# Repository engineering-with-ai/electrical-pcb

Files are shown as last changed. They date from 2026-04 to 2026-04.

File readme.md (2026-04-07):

# [electrical-pcb] ⚡




CM4 carrier board — Raspberry Pi Compute Module 4 carrier for an outdoor self-contained sensor system with computer vision, thermal imaging, cellular uplink, and solar + battery power. 5V screw terminal input, polyfuse + reverse polarity protection, CP2102N USB-UART debug, MAX3485 RS-485, I2C/SPI/GPIO headers on 2.54mm pitch, 100x80mm 2-layer board.

Foundation board that exposes raw CM4 interfaces via headers. Downstream boards connect RGB camera (CSI), FLIR Lepton thermal sensor (SPI), cellular modem (RS-485 Modbus), and solar charge controller (I2C BMS telemetry).

**[View generated deliverables](output/)**

## 📋 Board Spec

```mermaid
graph LR
    PWR["5V Screw Terminal"] --> FUSE["Polyfuse<br/>1812L200 2A"]
    FUSE --> FET["SI2301 P-FET<br/>Reverse Polarity"]
    FET --> RAIL["5V_RAIL"]
    RAIL --> CM4["CM4 Module<br/>Hirose DF40"]
    CM4 --> UART["CP2102N<br/>USB-UART Debug"]
    CM4 --> RS485["MAX3485<br/>RS-485"]
    CM4 --> I2C["I2C Header<br/>2.2k Pull-ups"]
    CM4 --> SPI["SPI Header"]
    CM4 --> GPIO["GPIO Header"]

    style PWR fill:#4a9,stroke:#333
    style FUSE fill:#a94,stroke:#333
    style FET fill:#a94,stroke:#333
    style RAIL fill:#4a9,stroke:#333
    style CM4 fill:#49a,stroke:#333
    style UART fill:#94a,stroke:#333
    style RS485 fill:#94a,stroke:#333
    style I2C fill:#94a,stroke:#333
    style SPI fill:#94a,stroke:#333
    style GPIO fill:#94a,stroke:#333
```

## 🔄 Workflow

```
theory.ipynb (sympy + pint) -> cad/model.py (SKiDL -> netlist) -> sim/ (power + signal integrity) -> pytest (assert vs theory)
```

1. `theory.ipynb` derives power rail budget, polyfuse margin, I2C pull-up selection, RS-485 bias
2. `cad/model.py` defines circuit in SKiDL, generates KiCad netlist
3. `sim/model.py` validates power rail voltage, I2C rise time, RS-485 bias
4. `sim/test_run.py` asserts simulation matches theory within tolerance
5. `/generate-schematic` generates professional `.kicad_sch` from netlist + `layout_spec.yaml`

## 🚀 Quick Start

```bash
uv sync
uv run poe checks          # black + ruff lint
uv run poe notebook         # execute theory.ipynb
uv run poe build            # SKiDL -> KiCad netlist + schematic
uv run poe sim              # 4/4 tests pass
```

## 🏭 Code to Fabrication

Everything is CLI or Claude skill except 3 manual steps marked with a wrench.

```
 1. uv run poe build                 → SKiDL netlist + schematic
 2. uv run poe sim                   → 4/4 tests pass
 3. /generate-schematic              → professional .kicad_sch
 4. uv run poe validate-model        → ERC 0 errors
 5. uv run poe generate-model        → schematic SVG + dark SVG + drawing PDF

    ┌──────────────────────────────────────────────────────┐
    │  HUMAN : open pcbnew, press F8, save, close          │
    └──────────────────────────────────────────────────────┘

 6. /layout-pcb                      → place + autoroute + ground pour + DRC + review SVG

    ┌──────────────────────────────────────────────────────┐
    │  HUMAN: review SVG, tweak pcb_placement.yaml, re-run │
    └──────────────────────────────────────────────────────┘

 7. uv run poe validate-asm          → DRC 0 errors
 8. uv run poe generate-asm          → gerbers + BOM + CPL + STEP
```

## 📁 Structure

- `theory.ipynb` — power budget + signal integrity derivation
- `sim/` — simulation + pytest assertions against theory
- `cad/netlist/` — SKiDL circuit definition (model.py, power.py, comms.py, io_headers.py)
- `cad/layout_spec.yaml` — schematic layout + block definitions
- `cad/pcb_placement.yaml` — AI-generated PCB component positions
- `cad/drawing-sheet.kicad_wks` — custom EWAI title block
- `cad/drawing/` — SVG dark mode conversion, PCB placement script
- `output/drawings/` — schematic SVGs (light + dark), drawing PDF
- `output/gerbers/` — fabrication gerbers + drill files
- `output/fab/` — BOM, CPL for assembly

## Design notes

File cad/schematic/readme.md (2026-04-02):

# cad/schematic/

Auto-generated by `/generate-schematic` — do not edit manually.
All `.py` files in this directory are replaced entirely each time the skill runs.

Run `/generate-schematic` to populate.

## Generated Files

| File | Purpose |
|---|---|
| `schematic.py` | Orchestrator — reads layout_spec.yaml, calls block placers, saves .kicad_sch |
| `sch_helpers.py` | Pin offsets, wiring utilities, power/label stub helpers |
| `sch_power.py` | Power input block (screw terminal, polyfuse, reverse polarity, bulk caps) |
| `sch_mcu.py` | MCU/processor connector block |
| `sch_comms.py` | Communication blocks (UART, RS-485, USB, CAN, etc.) |
| `sch_io.py` | I/O header blocks (I2C, SPI, GPIO, decoupling) |

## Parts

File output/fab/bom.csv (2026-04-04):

Designator | Comment | Footprint | Quantity
C1 | 100uF | Capacitor_SMD:C_1210_3225Metric | 1
C2 | 10uF | Capacitor_SMD:C_0805_2012Metric | 1
C3-C8 | 100nF | Capacitor_SMD:C_0402_1005Metric | 6
F1 | 2A | Fuse:Fuse_1812_4532Metric | 1
J1 | 5V_IN | Connector_PinHeader_2.54mm:PinHeader_1x02_P2.54mm_Vertical | 1
J2 | CM4 | Connector_PinHeader_2.54mm:PinHeader_2x20_P2.54mm_Vertical | 1
J3 | RS485 | Connector_PinHeader_2.54mm:PinHeader_1x04_P2.54mm_Vertical | 1
J4 | USB_DEBUG | Connector_USB:USB_Micro-B_Molex_47346-0001 | 1
J5 | I2C | Connector_PinHeader_2.54mm:PinHeader_1x04_P2.54mm_Vertical | 1
J6 | SPI | Connector_PinHeader_2.54mm:PinHeader_1x06_P2.54mm_Vertical | 1
J7 | GPIO | Connector_PinHeader_2.54mm:PinHeader_1x08_P2.54mm_Vertical | 1
Q1 | SI2301 | Package_TO_SOT_SMD:SOT-23 | 1
R1 | 120 | Resistor_SMD:R_0805_2012Metric | 1
R2,R3 | 560 | Resistor_SMD:R_0603_1608Metric | 2
R4,R5 | 2.2k | Resistor_SMD:R_0603_1608Metric | 2
U1 | MAX3485 | Package_SO:SOIC-8_3.9x4.9mm_P1.27mm | 1
U2 | CP2102N | Package_DFN_QFN:QFN-20-1EP_4x4mm_P0.5mm_EP2.5x2.5mm | 1

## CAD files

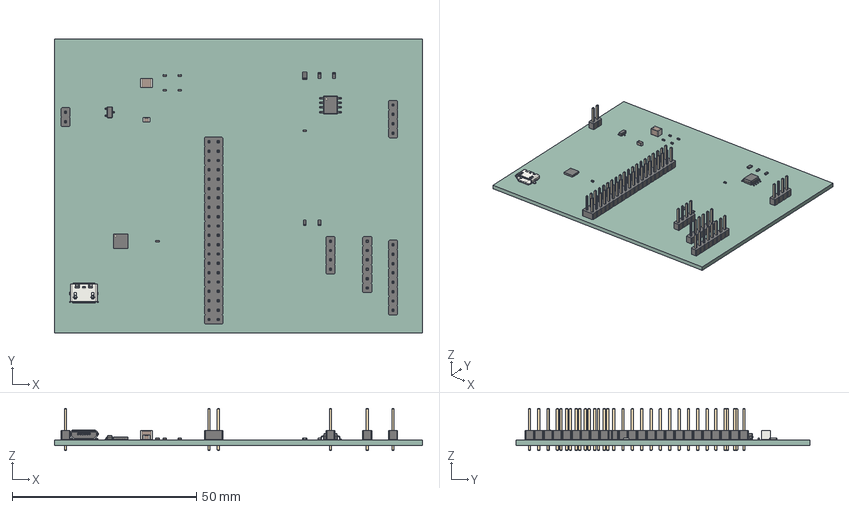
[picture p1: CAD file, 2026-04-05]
output/cm4_carrier_pcb.step
100.0 x 80.0 x 11.5 mm
C_0402_1005Metric x 6
USB_Micro-B_Molex_47346-0001
R_0603_1608Metric x 4
PinHeader_2x20_P2.54mm_Vertical
PinHeader_1x02_P2.54mm_Vertical
PinHeader_1x04_P2.54mm_Vertical x 2
C_0805_2012Metric
PinHeader_1x08_P2.54mm_Vertical
SOIC-8_3.9x4.9mm_P1.27mm
QFN-20-1EP_4x4mm_P0.5mm_EP2.5x2.5mm
PinHeader_1x06_P2.54mm_Vertical
SOT-23
R_0805_2012Metric
C_1210_3225Metric
cm4_carrier_PCB

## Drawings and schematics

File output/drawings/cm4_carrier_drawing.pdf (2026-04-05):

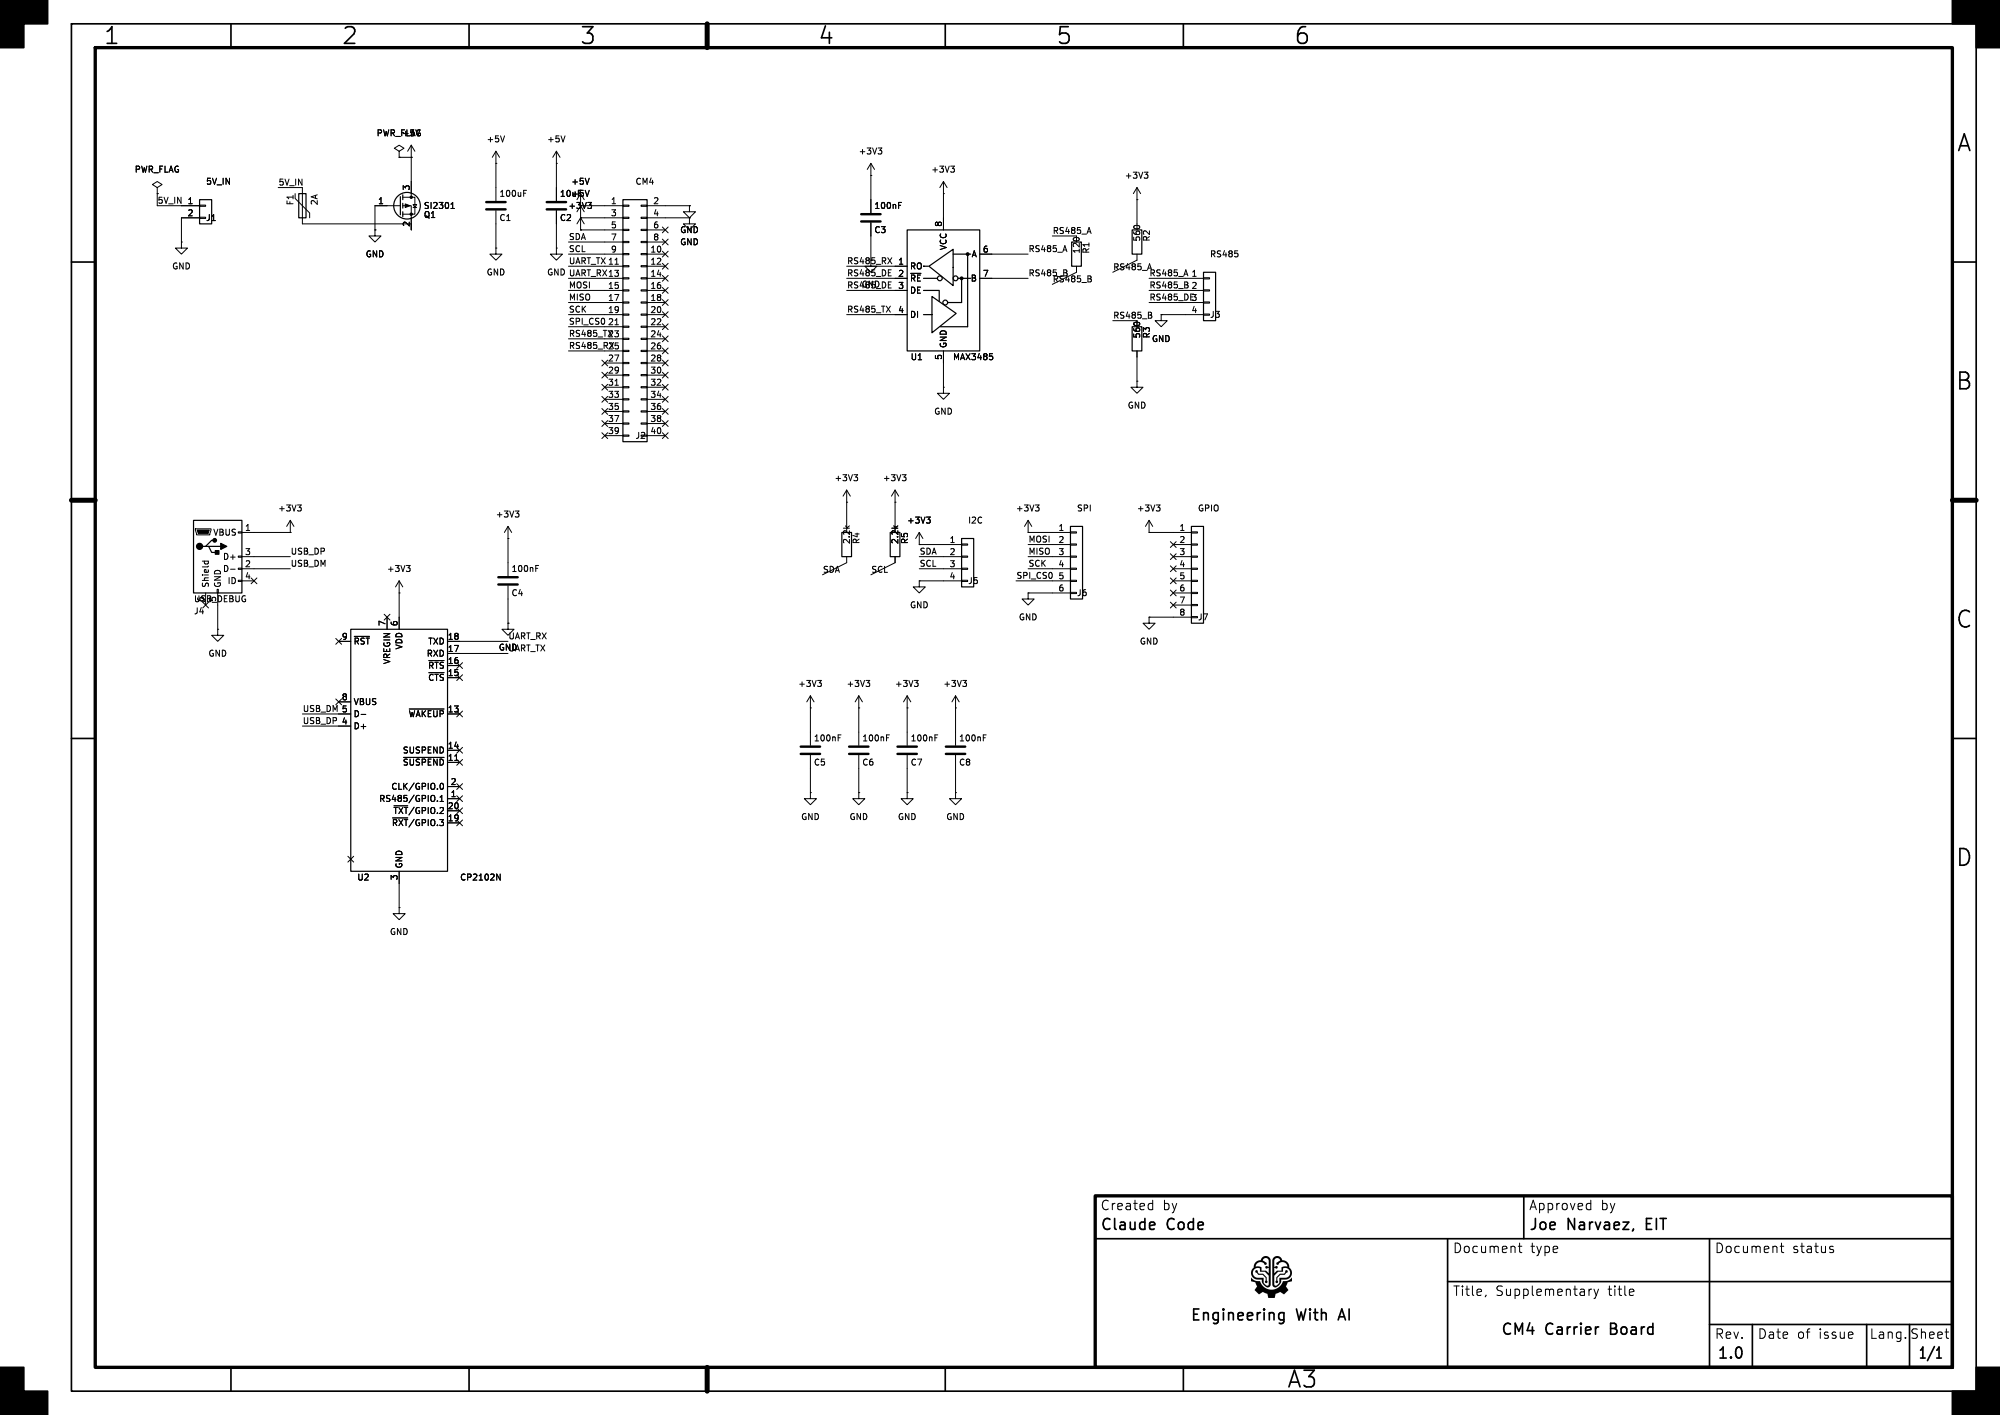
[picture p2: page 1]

3 TXD 18 RXD 17 ~{RTS} 16 ~{CTS} 15 ~{WAKEUP} 13 SUSPEND 14 ~{SUSPEND}11 CLK/GPIO.0 2 RS485/GPIO.1 1 ~{TXT}/GPIO.220 ~{RXT}/GPIO.319 U2 CP2102N GND

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

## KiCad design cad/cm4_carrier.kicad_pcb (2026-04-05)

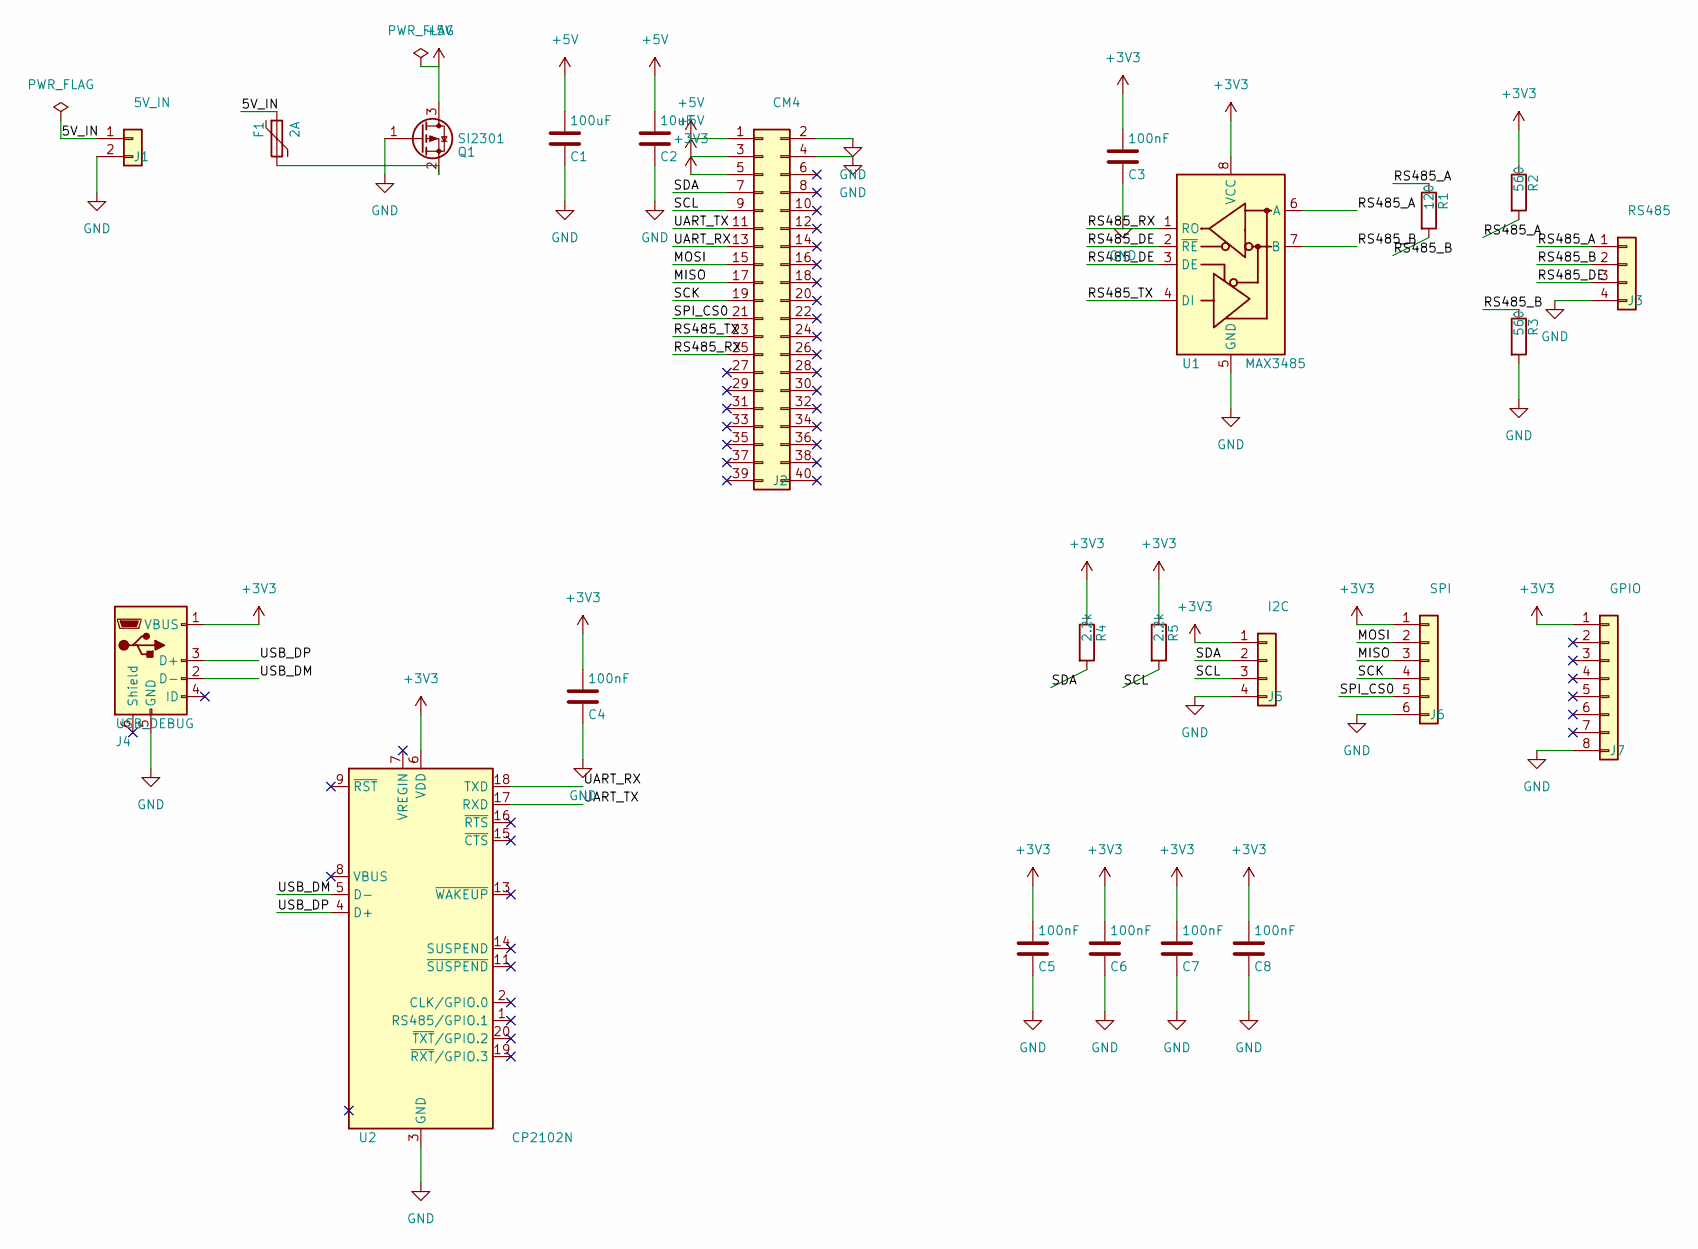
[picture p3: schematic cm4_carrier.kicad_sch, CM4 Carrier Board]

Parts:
C1: 100uF; C_1210_3225Metric
C2: 10uF; C_0805_2012Metric
C3, C4, C5, C6, C7, C8: 100nF; C_0402_1005Metric
F1: 2A; Fuse_1812_4532Metric
J1: 5V_IN; PinHeader_1x02_P2.54mm_Vertical
J2: CM4; PinHeader_2x20_P2.54mm_Vertical
J3: RS485; PinHeader_1x04_P2.54mm_Vertical
J4: USB_DEBUG; USB_Micro-B_Molex_47346-0001
J5: I2C; PinHeader_1x04_P2.54mm_Vertical
J6: SPI; PinHeader_1x06_P2.54mm_Vertical
J7: GPIO; PinHeader_1x08_P2.54mm_Vertical
Q1: SI2301; SOT-23
R1: 120; R_0805_2012Metric
R2, R3: 560; R_0603_1608Metric
R4, R5: 2.2k; R_0603_1608Metric
U1: MAX3485; SOIC-8_3.9x4.9mm_P1.27mm
U2: CP2102N; QFN-20-1EP_4x4mm_P0.5mm_EP2.5x2.5mm

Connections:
+3V3: C3.1, C4.1, C5.1, C6.1, C7.1, C8.1, J2.5, J4.1 (VBUS), J5.1, J6.1, J7.1, R2.1, R4.1, R5.1, U1.8 (VCC), U2.6 (VDD)
+5V: C1.1, C2.1, J2.1, J2.3, Q1.3 (D)
/5V_IN: F1.1, J1.1
/MISO: J2.17, J6.3
/MOSI: J2.15, J6.2
/RS485_A: J3.1, R1.1, R2.2, U1.6 (A)
/RS485_B: J3.2, R1.2, R3.1, U1.7 (B)
/RS485_DE: J3.3, U1.2 (~RE), U1.3 (DE)
/RS485_RX: J2.25, U1.1 (RO)
/RS485_TX: J2.23, U1.4 (DI)
/SCK: J2.19, J6.4
/SCL: J2.9, J5.3, R5.2
/SDA: J2.7, J5.2, R4.2
/SPI_CS0: J2.21, J6.5
/UART_RX: J2.13, U2.18 (TXD)
/UART_TX: J2.11, U2.17 (RXD)
/USB_DM: J4.2 (D-), U2.5 (D-)
/USB_DP: J4.3 (D+), U2.4 (D+)
GND: C1.2, C2.2, C3.2, C4.2, C5.2, C6.2, C7.2, C8.2, J1.2, J2.2, J2.4, J3.4, J4.5 (GND), J5.4, J6.6, J7.8, Q1.1 (G), R3.2, U1.5 (GND), U2.3 (GND), U2.12 (GND), U2.21 (GND)
unnamed: F1.2, Q1.2 (S)

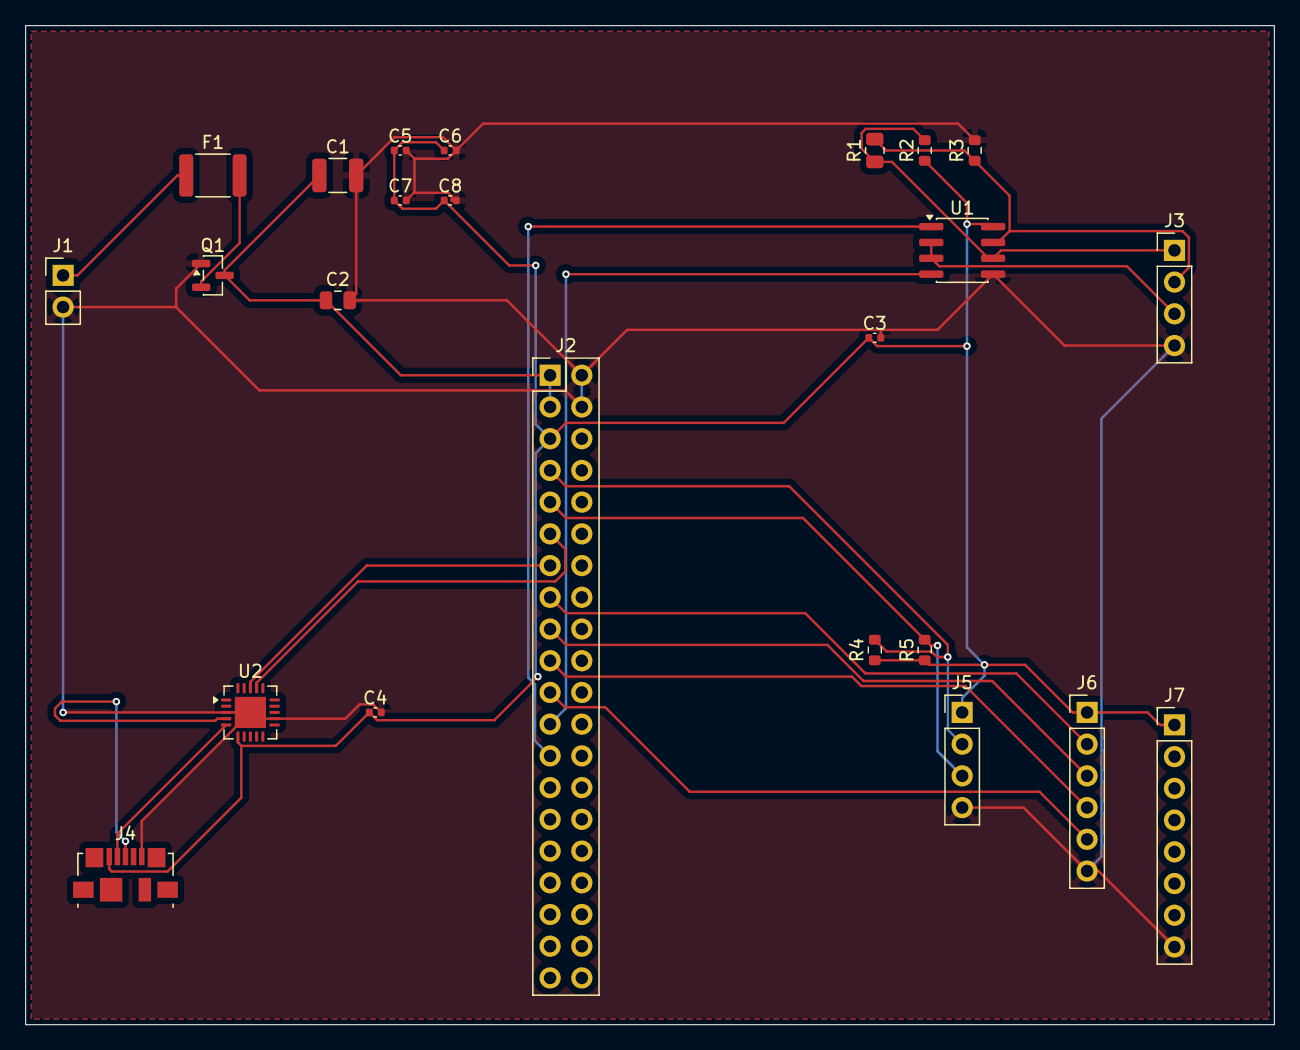
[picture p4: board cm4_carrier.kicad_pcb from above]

Board: 2 copper layers, 100.0 x 80.0 mm, 24 parts (0 on the bottom side), 20 nets.

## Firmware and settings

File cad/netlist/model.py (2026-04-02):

"""CM4 carrier board netlist generation.

SKiDL defines the circuit topology -> KiCad netlist.
Modular: power, comms, and I/O sections in separate files.
"""

import os

_SYM_DIR = "/usr/share/kicad/symbols"
for v in (
    "KICAD_SYMBOL_DIR",
    "KICAD6_SYMBOL_DIR",
    "KICAD7_SYMBOL_DIR",
    "KICAD8_SYMBOL_DIR",
    "KICAD9_SYMBOL_DIR",
):
    os.environ[v] = _SYM_DIR

import skidl  # noqa: E402

from cad.netlist.comms import build_rs485, build_usb_uart  # noqa: E402
from cad.netlist.io_headers import (  # noqa: E402
    build_gpio_header,
    build_i2c_header,
    build_spi_header,
)
from cad.netlist.power import build_power  # noqa: E402

NETLIST_PATH = "cad/cm4_carrier.net"


def build_netlist() -> None:
    """Define CM4 carrier board in SKiDL and generate KiCad netlist."""
    v5_in = skidl.Net("5V_IN")
    v5_rail = skidl.Net("5V_RAIL")
    v3v3 = skidl.Net("3V3")
    gnd = skidl.Net("GND")

    uart_tx = skidl.Net("UART_TX")
    uart_rx = skidl.Net("UART_RX")
    sda = skidl.Net("SDA")
    scl = skidl.Net("SCL")
    mosi = skidl.Net("MOSI")
    miso = skidl.Net("MISO")
    sck = skidl.Net("SCK")
    cs = skidl.Net("SPI_CS0")
    rs485_tx = skidl.Net("RS485_TX")
    rs485_rx = skidl.Net("RS485_RX")

    build_power(v5_in, v5_rail, gnd)
    _build_cm4_connector(
        v5_rail,
        v3v3,
        gnd,
        uart_tx,
        uart_rx,
        sda,
        scl,
        mosi,
        miso,
        sck,
        cs,
        rs485_tx,
        rs485_rx,
    )
    build_rs485(rs485_tx, rs485_rx, v3v3, gnd)
    build_usb_uart(uart_tx, uart_rx, v3v3, gnd)
    build_i2c_header(sda, scl, v3v3, gnd)
    build_spi_header(mosi, miso, sck, cs, v3v3, gnd)
    build_gpio_header(v3v3, gnd)
    _build_decoupling(v3v3, gnd, count=4)

    skidl.generate_netlist(file_=NETLIST_PATH, tool=skidl.KICAD8)


def _build_cm4_connector(
    v5_rail: skidl.Net,
    v3v3: skidl.Net,
    gnd: skidl.Net,
    uart_tx: skidl.Net,
    uart_rx: skidl.Net,
    sda: skidl.Net,
    scl: skidl.Net,
    mosi: skidl.Net,
    miso: skidl.Net,
    sck: skidl.Net,
    cs: skidl.Net,
    rs485_tx: skidl.Net,
    rs485_rx: skidl.Net,
) -> None:
    """CM4 module connector — 2x20 header as DF40 placeholder."""
    # Reason: Hirose DF40 100-pin not in standard KiCad libs
    j = skidl.Part(
        "Connector_Generic",
        "Conn_02x20_Odd_Even",
        footprint="Connector_PinHeader_2.54mm:PinHeader_2x20_P2.54mm_Vertical",
    )
    j.value = "CM4"
    # Reason: pin assignments per RPi CM4 datasheet GPIO header
    v5_rail += j[1]
    gnd += j[2]
    v5_rail += j[3]
    gnd += j[4]
    v3v3 += j[5]
    sda += j[7]
    scl += j[9]
    uart_tx += j[11]
    uart_rx += j[13]
    mosi += j[15]
    miso += j[17]
    sck += j[19]
    cs += j[21]
    rs485_tx += j[23]
    rs485_rx += j[25]


def _build_decoupling(v3v3: skidl.Net, gnd: skidl.Net, count: int) -> None:
    """Add 100nF decoupling caps for CM4."""
    for _ in range(count):
        c = skidl.Part(
            "Device",
            "C",
            value="100nF",
            footprint="Capacitor_SMD:C_0402_1005Metric",
        )
        v3v3 += c[1]
        gnd += c[2]


if __name__ == "__main__":
    build_netlist()
    print(f"Netlist: {NETLIST_PATH}")

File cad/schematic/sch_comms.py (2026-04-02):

# AUTO-GENERATED by /generate-schematic — do not edit manually.
# This file is replaced entirely each time the skill runs for a new circuit.
"""Communication blocks: RS-485 (MAX3485) and USB-UART (CP2102N)."""

from cad.schematic.sch_helpers import (
    CP2102N_PINS,
    MAX3485_PINS,
    USB_MICRO_PINS,
    c_pin,
    conn_1xn_pin,
    ic_pin,
    nc,
    r_pin,
    stub_label,
    stub_pwr,
)

FP_SOIC8 = "Package_SO:SOIC-8_3.9x4.9mm_P1.27mm"
FP_R_0805 = "Resistor_SMD:R_0805_2012Metric"
FP_R_0603 = "Resistor_SMD:R_0603_1608Metric"
FP_CONN_1X04 = "Connector_PinHeader_2.54mm:PinHeader_1x04_P2.54mm_Vertical"
FP_C_0402 = "Capacitor_SMD:C_0402_1005Metric"
FP_QFN20 = "Package_DFN_QFN:QFN-20-1EP_4x4mm_P0.5mm_EP2.5x2.5mm"
FP_USB_MICRO = "Connector_USB:USB_Micro-B_Molex_47346-0001"


def place_rs485_block(sch, bx: int, by: int, pwr: dict) -> None:
    """Place RS-485 transceiver block."""
    u1_pos = (bx + 22, by + 20)
    u1 = sch.components.add("Interface_UART:MAX3485", "U1", "MAX3485", position=u1_pos)
    u1.footprint = FP_SOIC8

    stub_label(sch, ic_pin(u1_pos, MAX3485_PINS, 1), "RS485_RX", dx=-8)
    stub_label(sch, ic_pin(u1_pos, MAX3485_PINS, 2), "RS485_DE", dx=-8)
    stub_label(sch, ic_pin(u1_pos, MAX3485_PINS, 3), "RS485_DE", dx=-8)
    stub_label(sch, ic_pin(u1_pos, MAX3485_PINS, 4), "RS485_TX", dx=-8)
    stub_pwr(sch, ic_pin(u1_pos, MAX3485_PINS, 8), "power:+3V3", pwr, dy=-4)
    stub_pwr(sch, ic_pin(u1_pos, MAX3485_PINS, 5), "power:GND", pwr, dy=4)
    stub_label(sch, ic_pin(u1_pos, MAX3485_PINS, 6), "RS485_A", dx=6, rotation=180)
    stub_label(sch, ic_pin(u1_pos, MAX3485_PINS, 7), "RS485_B", dx=6, rotation=180)

    r1_pos = (bx + 44, by + 14)
    r1 = sch.components.add("Device:R", "R1", "120", position=r1_pos)
    r1.footprint = FP_R_0805
    stub_label(sch, r_pin(r1_pos, 2), "RS485_A", dx=-4)
    stub_label(sch, r_pin(r1_pos, 1), "RS485_B", dx=-4, dy=2)

    r2_pos = (bx + 54, by + 12)
    r2 = sch.components.add("Device:R", "R2", "560", position=r2_pos)
    r2.footprint = FP_R_0603
    stub_pwr(sch, r_pin(r2_pos, 2), "power:+3V3", pwr, dy=-4)
    stub_label(sch, r_pin(r2_pos, 1), "RS485_A", dx=-4, dy=2)

    r3_pos = (bx + 54, by + 28)
    r3 = sch.components.add("Device:R", "R3", "560", position=r3_pos)
    r3.footprint = FP_R_0603
    stub_label(sch, r_pin(r3_pos, 2), "RS485_B", dx=-4)
    stub_pwr(sch, r_pin(r3_pos, 1), "power:GND", pwr, dy=4)

    j3_pos = (bx + 66, by + 20)
    j3 = sch.components.add(
        "Connector_Generic:Conn_01x04", "J3", "RS485", position=j3_pos
    )
    j3.footprint = FP_CONN_1X04
    stub_label(sch, conn_1xn_pin(j3_pos, 4, 1), "RS485_A", dx=-6)
    stub_label(sch, conn_1xn_pin(j3_pos, 4, 2), "RS485_B", dx=-6)
    stub_label(sch, conn_1xn_pin(j3_pos, 4, 3), "RS485_DE", dx=-6)
    stub_pwr(sch, conn_1xn_pin(j3_pos, 4, 4), "power:GND", pwr, dx=-4, dy=0)

    c3_pos = (bx + 10, by + 8)
    c3 = sch.components.add("Device:C", "C3", "100nF", position=c3_pos)
    c3.footprint = FP_C_0402
    stub_pwr(sch, c_pin(c3_pos, 1), "power:+3V3", pwr, dy=-4)
    stub_pwr(sch, c_pin(c3_pos, 2), "power:GND", pwr, dy=4)


def place_usb_uart_block(sch, bx: int, by: int, pwr: dict) -> None:
    """Place USB-UART bridge block."""
    # Reason: y-offset +40 avoids J4.GND and U2.TXD sharing exact y-coordinate
    u2_pos = (bx + 36, by + 40)
    u2 = sch.components.add(
        "Interface_USB:CP2102N-Axx-xQFN20", "U2", "CP2102N", position=u2_pos
    )
    u2.footprint = FP_QFN20

    stub_pwr(sch, ic_pin(u2_pos, CP2102N_PINS, 6), "power:+3V3", pwr, dy=-4)
    stub_pwr(sch, ic_pin(u2_pos, CP2102N_PINS, 3), "power:GND", pwr, dy=4)
    stub_label(sch, ic_pin(u2_pos, CP2102N_PINS, 4), "USB_DP", dx=-6)
    stub_label(sch, ic_pin(u2_pos, CP2102N_PINS, 5), "USB_DM", dx=-6)
    stub_label(sch, ic_pin(u2_pos, CP2102N_PINS, 17), "UART_TX", dx=8, rotation=180)
    stub_label(sch, ic_pin(u2_pos, CP2102N_PINS, 18), "UART_RX", dx=8, rotation=180)

    used = {3, 4, 5, 6, 12, 17, 18, 21}
    for pin_num in range(1, 22):
        if pin_num not in used:
            nc(sch, ic_pin(u2_pos, CP2102N_PINS, pin_num))

    j4_pos = (bx + 6, by + 8)
    j4 = sch.components.add("Connector:USB_B_Micro", "J4", "USB_DEBUG", position=j4_pos)
    j4.footprint = FP_USB_MICRO

    stub_pwr(sch, ic_pin(j4_pos, USB_MICRO_PINS, 1), "power:+3V3", pwr, dx=6, dy=0)
    stub_label(sch, ic_pin(j4_pos, USB_MICRO_PINS, 3), "USB_DP", dx=6, rotation=180)
    stub_label(sch, ic_pin(j4_pos, USB_MICRO_PINS, 2), "USB_DM", dx=6, rotation=180)
    stub_pwr(sch, ic_pin(j4_pos, USB_MICRO_PINS, 5), "power:GND", pwr, dy=4)
    nc(sch, ic_pin(j4_pos, USB_MICRO_PINS, 4))
    nc(sch, ic_pin(j4_pos, USB_MICRO_PINS, 6))

    c4_pos = (bx + 54, by + 12)
    c4 = sch.components.add("Device:C", "C4", "100nF", position=c4_pos)
    c4.footprint = FP_C_0402
    stub_pwr(sch, c_pin(c4_pos, 1), "power:+3V3", pwr, dy=-4)
    stub_pwr(sch, c_pin(c4_pos, 2), "power:GND", pwr, dy=4)

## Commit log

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2026-03-22 ♻️ refactor: replace RC circuit with buck converter
    - SKiDL circuit definition in cad/model.py → KiCad netlist
    - PySpice switching transient sim (12V→3.3V, 500kHz)
    - Aligned poe tasks: build, inspect, export, validate
    - Moved drawings to spec/drawings/
    - Added skidl dependency
    [constants.py, model.py, test_run.py]
2026-03-22 🔥 chore: remove RC circuit artifacts, add buck theory.ipynb + readme
    [rc_charging.kicad_sch]
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2026-03-22 ✨ feat: generate schematic via kicad-sch-api + SVG export
    - kicad-sch-api generates .kicad_sch from Python (KiCad 9 compatible)
    - SKiDL generates netlist for PySpice + PCB
    - kicad-cli exports schematic SVG to spec/drawings/
    - Added .gitignore for SKiDL temp files
    [buck_converter.kicad_sch]
2026-03-23 ✨ feat: align poe tasks, fix ERC, add ISO title block with logo
    Rename poe tasks for symmetry: inspect→inspect-model, export→drawings,
    validate→validate-model. Add inspect-asm for pcbnew. Fix all 16 ERC
    violations by correcting schematic wiring and adding PWR_FLAG symbols.
    Custom ISO 7200 drawing sheet with EWAI logo, approval chain. SVG
    exports circuit-only for web, PDF includes full title block. Fix lint
    errors (unused imports, ambiguous var names, notebook naming).
    [buck_converter.kicad_sch]
2026-03-23 🔧 fix: use 2N7002 symbol for correct SOT-23 pin mapping
    Device:Q_NMOS uses pin numbers G/D/S which don't match SOT-23 pad
    numbers 1/2/3. Switched to Transistor_FET:2N7002 (extends Q_NMOS_GSD)
    which maps G→1, S→2, D→3. PCB import now works. Added footprints to
    schematic components. inspect-asm opens project manager for pcbnew
    context.
    [buck_converter.kicad_sch]
2026-03-23 🙈 chore: gitignore KiCad temp files
    Ignore .kicad_prl (UI prefs), backups, lock files, footprint cache,
    and ERC reports — all regenerated, not needed for cloning.
2026-03-23 ✨ feat: full PCB export pipeline — gerbers, drill, STEP, SVG
    drawings task now exports PCB deliverables when .kicad_pcb exists:
    gerbers + drill for fab, STEP for mechanical integration, SVG for docs.
    validate-model runs DRC alongside ERC. Schematic SVG strips drawing
    sheet for web, PDF keeps ISO title block.
    [buck_converter-B_Courtyard.gbr, buck_converter-B_Cu.gbl, buck_converter-B_Fab.gbr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]
2026-03-24 🔧 chore: rename electrical-base → electrical-pcb
    Update project name, readme badges, and GitHub mirror URL.
2026-03-24 🔒 fix: bump black to 26.3.1 (CVE-2026-32274)
2026-03-24 ✨ feat: rewrite constants.py for CM4 carrier board
    Replace buck converter parameters with CM4 carrier board specs:
    power rail (5V input, polyfuse, reverse polarity MOSFET), RS-485
    (MAX3485 termination/bias), I2C (fast mode pull-up calculation).
    All values sourced from datasheets with pint units + uncertainties.
    [constants.py]
2026-03-24 ✨ feat: rewrite theory.ipynb for CM4 carrier board
    Two-section derivation:
    1. Power rail budget — V_rail at typical (4.78V) and peak (4.54V) load,
    polyfuse margin (I_typical/I_hold = 0.70)
    2. Signal integrity — I2C pull-up 2.2kOhm (186ns rise time < 300ns max),
    RS-485 termination 120 Ohm + 560 Ohm bias (319mV > 200mV threshold)
    Design note: 3A peak drops below CM4 4.75V minimum — acceptable for
    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
2026-03-24 ✨ feat: TDD sim + tests for CM4 carrier board
    4 assertions against theory.ipynb expected values:
    - Power rail voltage > 4.75V at typical 1.4A load
    - Polyfuse margin: I_typical/I_hold = 0.70 < 1
    - I2C rise time 186ns < 300ns max (2.2kOhm pull-up, 100pF bus)
    - RS-485 idle bias 319mV > 200mV threshold (560 Ohm bias, 120 Ohm term)
    All 4 pass. Simulations use analytical models matching theory notebook
    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
2026-03-24 ✨ feat: SKiDL netlist for CM4 carrier board
    Modular circuit definition:
    - power.py: screw terminal, polyfuse (1812L200), SI2301 P-FET, bulk caps
    - comms.py: MAX3485 RS-485 with termination/bias, CP2102N USB-UART
    - io_headers.py: I2C (2.2k pull-ups), SPI, GPIO headers (2.54mm)
    - model.py: CM4 connector (2x20 placeholder for DF40), assembly
    Netlist generates cleanly (0 errors). 4/4 sim tests still pass.
    [comms.py, io_headers.py, model.py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]
2026-03-24 🔧 chore: update pyproject + readme for CM4 carrier, delete buck_converter
    Replace all buck_converter references with cm4_carrier in poe tasks.
    Update readme with CM4 carrier board spec and mermaid diagram.
    Delete old buck_converter KiCad files and gerbers.
    [buck_converter-B_Courtyard.gbr, buck_converter-B_Cu.gbl, buck_converter-B_Fab.gbr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]
2026-03-24 ✨ feat: kicad-sch-api schematic generation for CM4 carrier
    Code-generated schematic with 5 functional groups: power input
    (polyfuse + MOSFET), CM4 connector (2x20), MAX3485 RS-485 with
    termination/bias, CP2102N USB-UART, I/O headers (I2C + SPI + GPIO).
    Components placed by section, net labels connect across groups.
    poe build now generates both netlist and schematic. poe drawings
    exports SVG + PDF.
    [cm4_carrier.kicad_sch]
2026-03-25 🐛 fix: correct CP2102N footprint to QFN-20 4x4mm
    The 3x3mm QFN-20 footprint doesn't exist in KiCad libraries.
    CP2102N uses QFN-20-1EP_4x4mm_P0.5mm_EP2.5x2.5mm.
    [cm4_carrier.kicad_sch]
2026-03-31 ✨ feat: add /generate-schematic skill + declarative layout spec
    Reusable Claude Code skill for professional schematic generation:
    - Phase 1: deterministic placement from layout_spec.yaml
    - Phase 2: visual review loop (render PNG, inspect, adjust, repeat)
    - layout_spec.yaml defines functional blocks, positions, signal flow
    - Skill enforces: power top/GND bottom, manhattan routing, min spacing
2026-03-31 ✨ feat: layout-spec-driven schematic with visual review
    Schematic generation now reads cad/layout_spec.yaml for block positions.
    Six blocks with clear separation: power (top-left), CM4 (top-center),
    RS-485 (top-right), USB-UART (bot-left), decoupling (bot-center),
    I/O headers (bot-right). Power symbols at top, GND at bottom per block.
    Visual review confirms legible layout with no major overlaps.
    [cm4_carrier.kicad_sch]
2026-04-01 ✨ feat: full code-to-fabrication pipeline with /generate-schematic skill
    - Split cad/ into netlist/ (source) and schematic/ (generated, gitignored)
    - Add generate-model/generate-asm poe tasks (replace drawings), align EE+ME
    - Add validate-asm (DRC) alongside validate-model (ERC)
    - Move output from spec/drawings/ to output/ (drawings/, gerbers/, STEP)
    - Sheet size from layout_spec.yaml (A3), %Z auto-fills drawing sheet
    - Margin offset (30,28) clears sheet border
    - Y-coordinate coincidence bug workaround for KiCad ERC
    - SKILL.md with all lessons learned, ships with repo
    - readme documents full workflow: /generate-schematic → validate → inspect → generate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
    [cm4_carrier.kicad_pcb, cm4_carrier.kicad_sch]
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2026-04-02 🔧 chore: untrack cad/schematic/ — generated by /generate-schematic
    These files are gitignored and fully regenerated each run.
2026-04-02 📝 docs: add cad/schematic/readme.md with generated file manifest
    Breadcrumb for fresh clones — shows what /generate-schematic produces.
2026-04-02 🐛 fix: remove schematic import from build task
    build (netlist) must not depend on cad/schematic/ which is generated
    separately by /generate-schematic and not tracked in git.
    [model.py]
2026-04-03 ✨ feat: track schematic + output artifacts for GitLab visibility
    - Un-gitignore cad/schematic/, output/, *.kicad_sch, *.net
    - Add generated schematic code (sch_power, sch_mcu, sch_comms, sch_io, sch_helpers)
    - Add output/drawings/ (schematic SVG + PDF)
    - Add output/gerbers/ (full gerber + drill set)
    - Add output/ STEP file
    - Replace black with ruff format (aligned with mechanical-model)
    All checks pass, 4/4 sim tests pass.
    [cm4_carrier-B_Courtyard.gbr, cm4_carrier-B_Cu.gbl, cm4_carrier-B_Fab.gbr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]
2026-04-04 feat: add dark-mode SVG, rename outputs, switch to black formatter
    - Add svg_dark.py for black↔white SVG color inversion
    - Rename: *_web.svg (no border), *_web_dark.svg, *_drawing.pdf
    - Switch formatter from ruff to black (align with python-base)
    - Add BOM + CPL to output/fab/
    [bom.csv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]
2026-04-05 feat: add /route-pcb skill for Freerouting autoroute pipeline
    DSN export (pcbnew) -> Freerouting CLI (headless) -> SES import -> DRC.
    Includes placement guidelines, ground pour checklist, troubleshooting.
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2026-04-05 refactor: consolidate place-pcb + route-pcb into single layout-pcb skill
    One skill: place (yaml) → route (Freerouting) → DRC → visual review.
    Human prerequisite (F8) at start, human review at end — no manual step
    in the middle.
2026-04-05 feat: automate ground pour in layout-pcb skill, reduce to 2 human touch points
    Ground pour (GND zones on F.Cu + B.Cu) now done via pcbnew Python API.
    No manual pcbnew step needed.
2026-04-05 feat: add PCB placement pipeline + routed board with ground pour
    Adds place_pcb.py for programmatic footprint placement from layout_spec.yaml,
    includes fully routed board via Freerouting with ground pour on both layers.
    [cm4_carrier-B_Courtyard.gbr, cm4_carrier-B_Cu.gbl, cm4_carrier-B_Fab.gbr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]
2026-04-05 ♻️ refactor: split pcb_placement.yaml from layout_spec, skill owns placement
    - layout_spec.yaml is human config, pcb_placement.yaml is AI-generated
    - place_pcb.py simplified to read/place/clear — no compute_placement algorithm
    - /layout-pcb skill reads netlist connectivity and places components intelligently
    - place_pcb.py clears stale traces before placing (root cause of prior DRC failures)
    - Full clean-slate pipeline: 0 violations, 0 unconnected on first attempt
    [cm4_carrier-B_Courtyard.gbr, cm4_carrier-B_Cu.gbl, cm4_carrier-B_Fab.gbr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]
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2026-04-10 📝 docs: recompose CLAUDE.md from context-mgmt
    Sync with upstream prompt fragments: terse comment tone,
    never-assume-bugs rule, React hooks convention.
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
